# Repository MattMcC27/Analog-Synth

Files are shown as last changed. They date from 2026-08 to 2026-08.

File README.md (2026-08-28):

# Analog-Synth

My personal Analog Voltage Controlled Oscilator, wave shapers, and output stage
<p align="center">
  
</p>  

<p align="center">
  
</p>  

## Behavior

## Wave Shape Photos at decreasing frequency

<p align="center">
  
  
  
</p>  
<p align="center">
  
  
  
</p>  
<p align="center">
  
  
  
</p>  
<p align="center">
  
  
  
</p>  
<p align="center">
  
  
  
</p>  
<p align="center">
  
</p>  

## Audio Demo

https://github.com/user-attachments/assets/6dd11a05-b424-4769-ac00-267ce8dbd173

https://github.com/user-attachments/assets/6da5949c-7cdd-406b-b645-f12ac689b7d8

https://github.com/user-attachments/assets/ecf994ba-5ef1-4e04-878b-3f7e2e97198b

https://github.com/user-attachments/assets/66918d8a-2ba2-4e4a-80ee-363ddde3f1d2

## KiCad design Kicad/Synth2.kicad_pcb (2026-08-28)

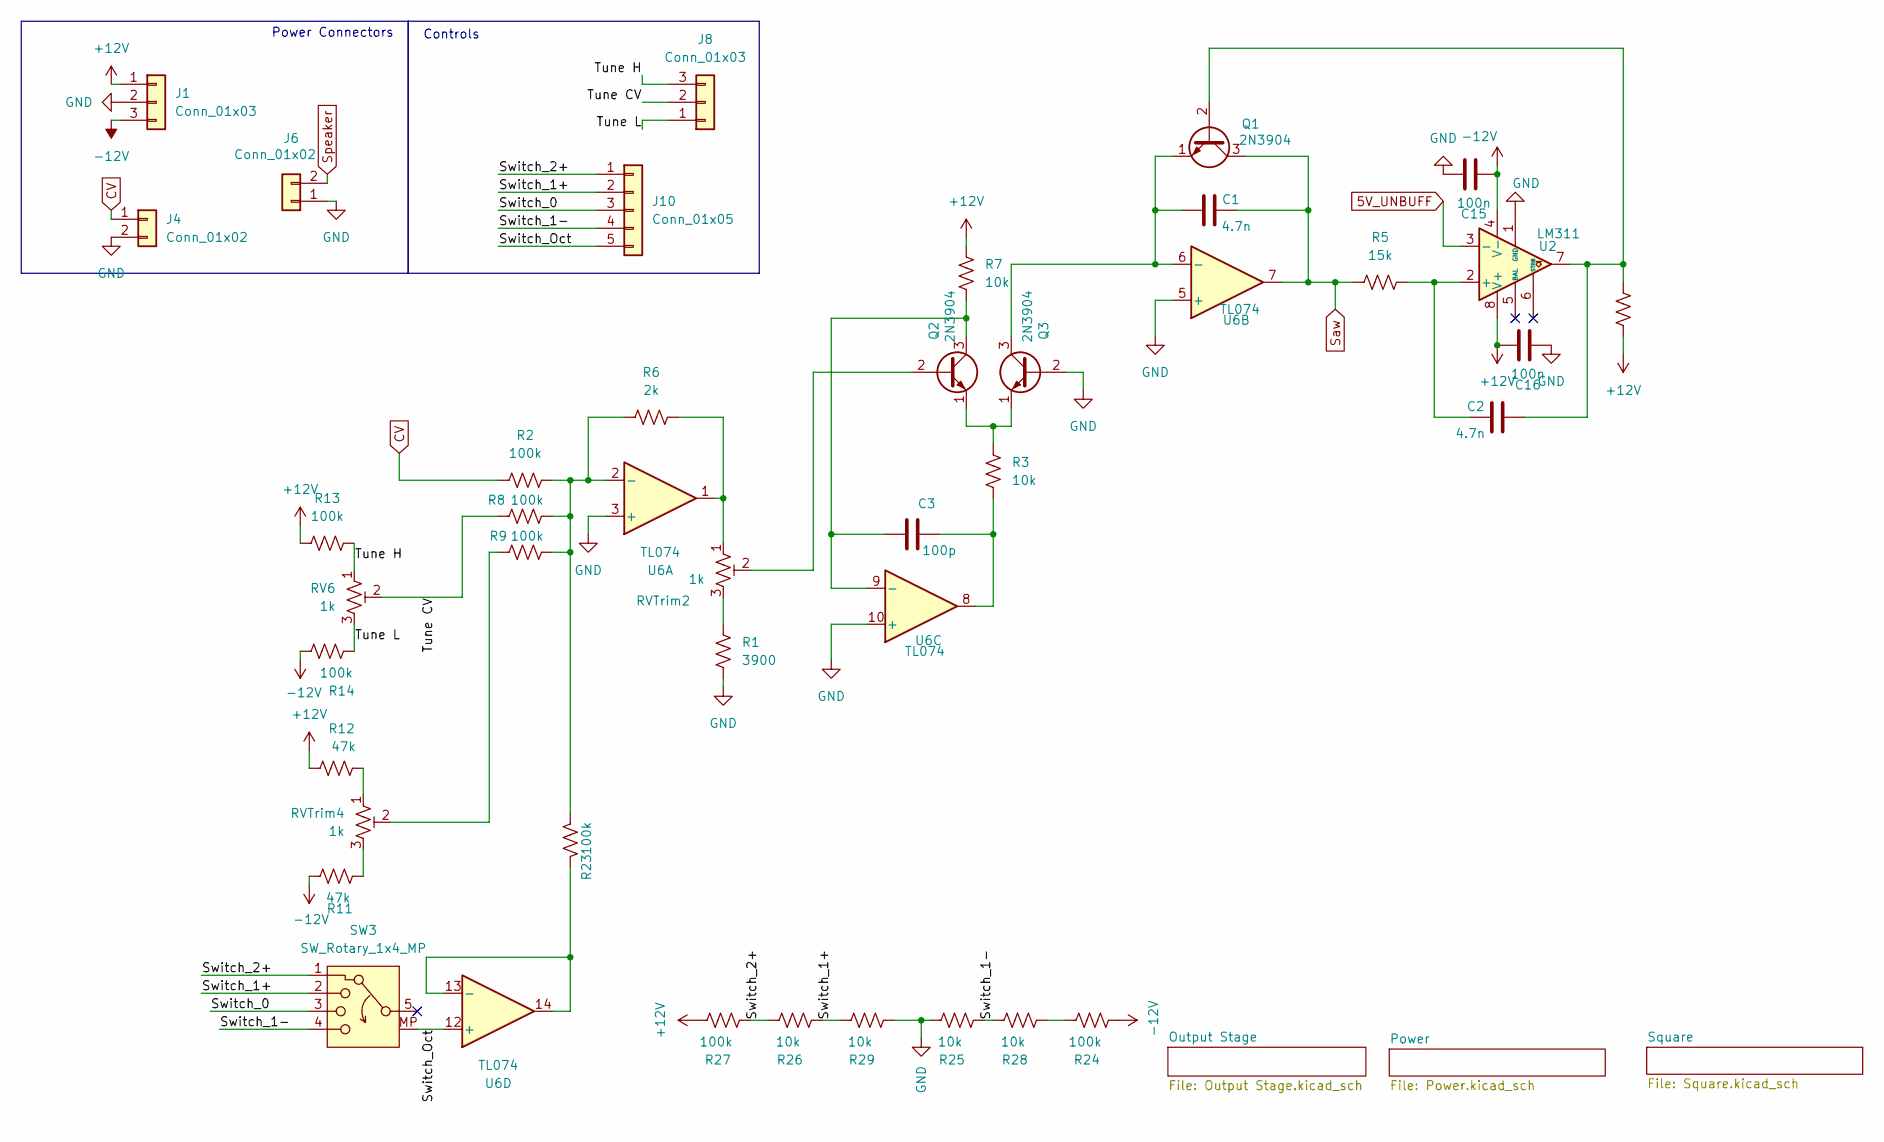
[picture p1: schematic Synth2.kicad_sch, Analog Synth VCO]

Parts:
C1, C2: 4.7n; C_Disc_D5.0mm_W2.5mm_P5.00mm
C3: 100p; C_Disc_D5.0mm_W2.5mm_P5.00mm
C15, C16: 100n; C_Disc_D5.0mm_W2.5mm_P5.00mm
J1, J8: Conn_01x03; JST_XH_B3B-XH-A_1x03_P2.50mm_Vertical
J4, J6: Conn_01x02; JST_XH_B2B-XH-A_1x02_P2.50mm_Vertical
J10: Conn_01x05; JST_XH_B5B-XH-A_1x05_P2.50mm_Vertical
Q1, Q2, Q3: 2N3904; MYNPN
R1: 3900; R_Axial_DIN0207_L6.3mm_D2.5mm_P7.62mm_Horizontal
R2, R8, R9, R13, R14, R23, R24, R27: 100k; R_Axial_DIN0207_L6.3mm_D2.5mm_P7.62mm_Horizontal
R3, R4, R7, R25, R26, R28, R29: 10k; R_Axial_DIN0207_L6.3mm_D2.5mm_P7.62mm_Horizontal
R5: 15k; R_Axial_DIN0207_L6.3mm_D2.5mm_P7.62mm_Horizontal
R6: 2k; R_Axial_DIN0207_L6.3mm_D2.5mm_P7.62mm_Horizontal
R11, R12: 47k; R_Axial_DIN0207_L6.3mm_D2.5mm_P7.62mm_Horizontal
RV6: 1k
RVTrim2, RVTrim4: 1k; Potentiometer_Bourns_3296W_Vertical
SW3: SW_Rotary_1x4_MP
U2: LM311; MY311
U6: TL074; MYTL074

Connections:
5V_UNBUFF: U2.3 (-); also elsewhere on the board
+12V: C16.2, J1.1, R4.1, R7.1, R12.2, R13.2, R27.1, U2.8 (V+); also elsewhere on the board
-12V: C15.1, J1.3, R11.2, R14.2, R24.2, U2.4 (V-); also elsewhere on the board
/Switch_0: J10.3, SW3.3
/Switch_1+: J10.2, R26.2, R29.1, SW3.2
/Switch_1-: J10.4, R25.2, R28.1, SW3.4
/Switch_2+: J10.1, R26.1, R27.2, SW3.1
/Switch_Oct: J10.5, SW3.MP, U6.12 (+)
/Tune CV: J8.2, R8.1, RV6.2
/Tune H: J8.3, R13.1, RV6.1
/Tune L: J8.1, R14.1, RV6.3
CV: J4.1, R2.1
GND: C15.2, C16.1, J1.2, J4.2, J6.1, Q3.2 (B), R1.2, R25.1, R29.2, U2.1 (GND), U6.3 (+), U6.5 (+), U6.10 (+); also elsewhere on the board
unnamed: C3.2, R3.2, U6.8
unnamed: C2.1, Q1.2 (B), R4.2, U2.7
unnamed: C1.1, Q1.1 (E), Q3.3 (C), U6.6 (-)
unnamed: Q2.2 (B), RVTrim2.2
unnamed: C3.1, Q2.3 (C), R7.2, U6.9 (-)
unnamed: Q2.1 (E), Q3.1 (E), R3.1
unnamed: R1.1, RVTrim2.3
unnamed: R6.2, RVTrim2.1, U6.1
unnamed: R9.1, RVTrim4.2
unnamed: R11.1, RVTrim4.3
unnamed: R12.1, RVTrim4.1
unnamed: R24.1, R28.2
unnamed: C2.2, R5.1, U2.2 (+)
unnamed: R2.2, R6.1, R8.2, R9.2, R23.2, U6.2 (-)
unnamed: R23.1, U6.13 (-), U6.14
Saw: C1.2, Q1.3 (C), R5.2, U6.7; also elsewhere on the board
Speaker: J6.2; also elsewhere on the board

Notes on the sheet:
Power Connectors
Controls

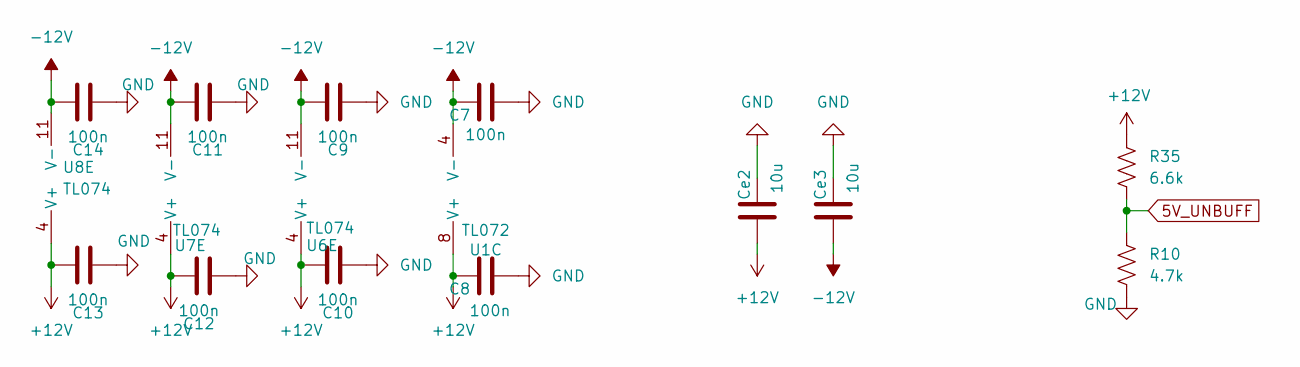
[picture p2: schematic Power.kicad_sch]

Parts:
C7, C8, C9, C10, C11, C12, C13, C14: 100n; C_Disc_D5.0mm_W2.5mm_P5.00mm
Ce2, Ce3: 10u; CP_Radial_D5.0mm_P2.50mm
R10: 4.7k; R_Axial_DIN0207_L6.3mm_D2.5mm_P7.62mm_Horizontal
R35: 6.6k; R_Axial_DIN0207_L6.3mm_D2.5mm_P7.62mm_Horizontal
U1: TL072; MYTL072
U6, U7, U8: TL074; MYTL074

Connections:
5V_UNBUFF: R10.2, R35.1; also elsewhere on the board
+12V: C8.2, C10.2, C12.1, C13.2, Ce2.1, R35.2, U1.8 (V+), U6.4 (V+), U7.4 (V+), U8.4 (V+); also elsewhere on the board
-12V: C7.2, C9.2, C11.2, C14.2, Ce3.1, U1.4 (V-), U6.11 (V-), U7.11 (V-), U8.11 (V-); also elsewhere on the board
GND: C7.1, C8.1, C9.1, C10.1, C11.1, C12.2, C13.1, C14.1, Ce2.2, Ce3.2, R10.1; also elsewhere on the board

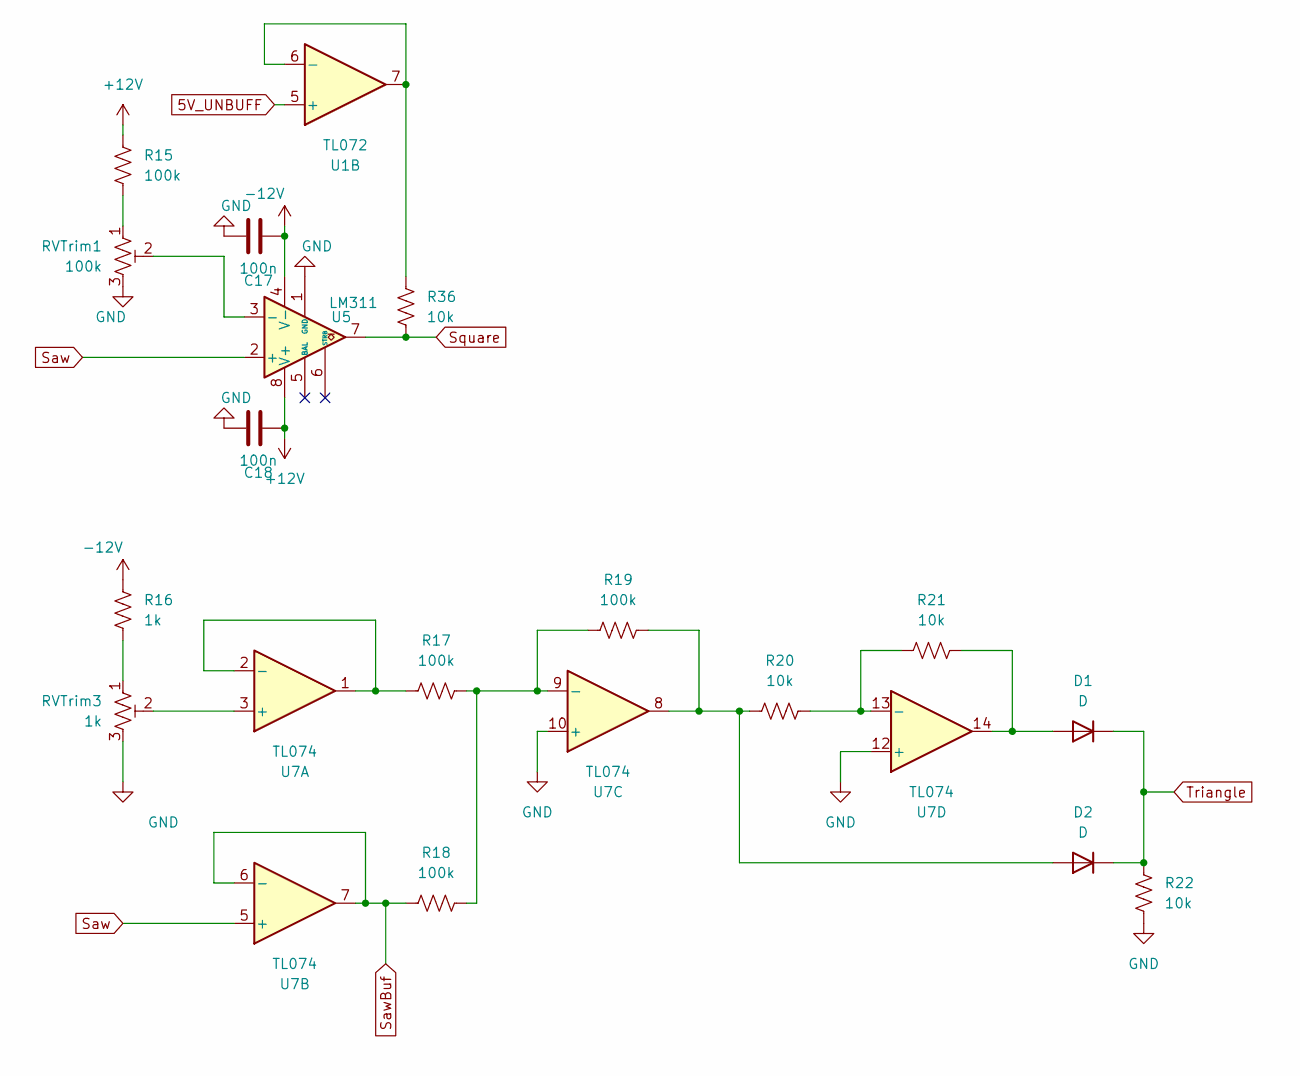
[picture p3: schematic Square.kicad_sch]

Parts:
C17, C18: 100n; C_Disc_D5.0mm_W2.5mm_P5.00mm
D1, D2: D; MYDIODE2
R15, R17, R18, R19: 100k; R_Axial_DIN0207_L6.3mm_D2.5mm_P7.62mm_Horizontal
R16: 1k; R_Axial_DIN0207_L6.3mm_D2.5mm_P7.62mm_Horizontal
R20, R21, R22, R36: 10k; R_Axial_DIN0207_L6.3mm_D2.5mm_P7.62mm_Horizontal
RVTrim1: 100k; Potentiometer_Bourns_3296W_Vertical
RVTrim3: 1k; Potentiometer_Bourns_3296W_Vertical
U1: TL072; MYTL072
U5: LM311; MY311
U7: TL074; MYTL074

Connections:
5V_UNBUFF: U1.5 (+); also elsewhere on the board
+12V: C18.1, R15.2, U5.8 (V+); also elsewhere on the board
-12V: C17.1, R16.2, U5.4 (V-); also elsewhere on the board
GND: C17.2, C18.2, R22.2, RVTrim1.3, RVTrim3.3, U5.1 (GND), U7.10 (+), U7.12 (+); also elsewhere on the board
unnamed: D1.2 (A), R21.1, U7.14
unnamed: D2.2 (A), R19.1, R20.2, U7.8
unnamed: R15.1, RVTrim1.1
unnamed: R16.1, RVTrim3.1
unnamed: R36.2, U1.6 (-), U1.7
unnamed: RVTrim1.2, U5.3 (-)
unnamed: RVTrim3.2, U7.3 (+)
unnamed: R17.2, U7.1, U7.2 (-)
unnamed: R17.1, R18.1, R19.2, U7.9 (-)
unnamed: R20.1, R21.2, U7.13 (-)
Saw: U5.2 (+), U7.5 (+); also elsewhere on the board
SawBuf: R18.2, U7.6 (-), U7.7; also elsewhere on the board
Square: R36.1, U5.7; also elsewhere on the board
Triangle: D1.1 (K), D2.1 (K), R22.1; also elsewhere on the board

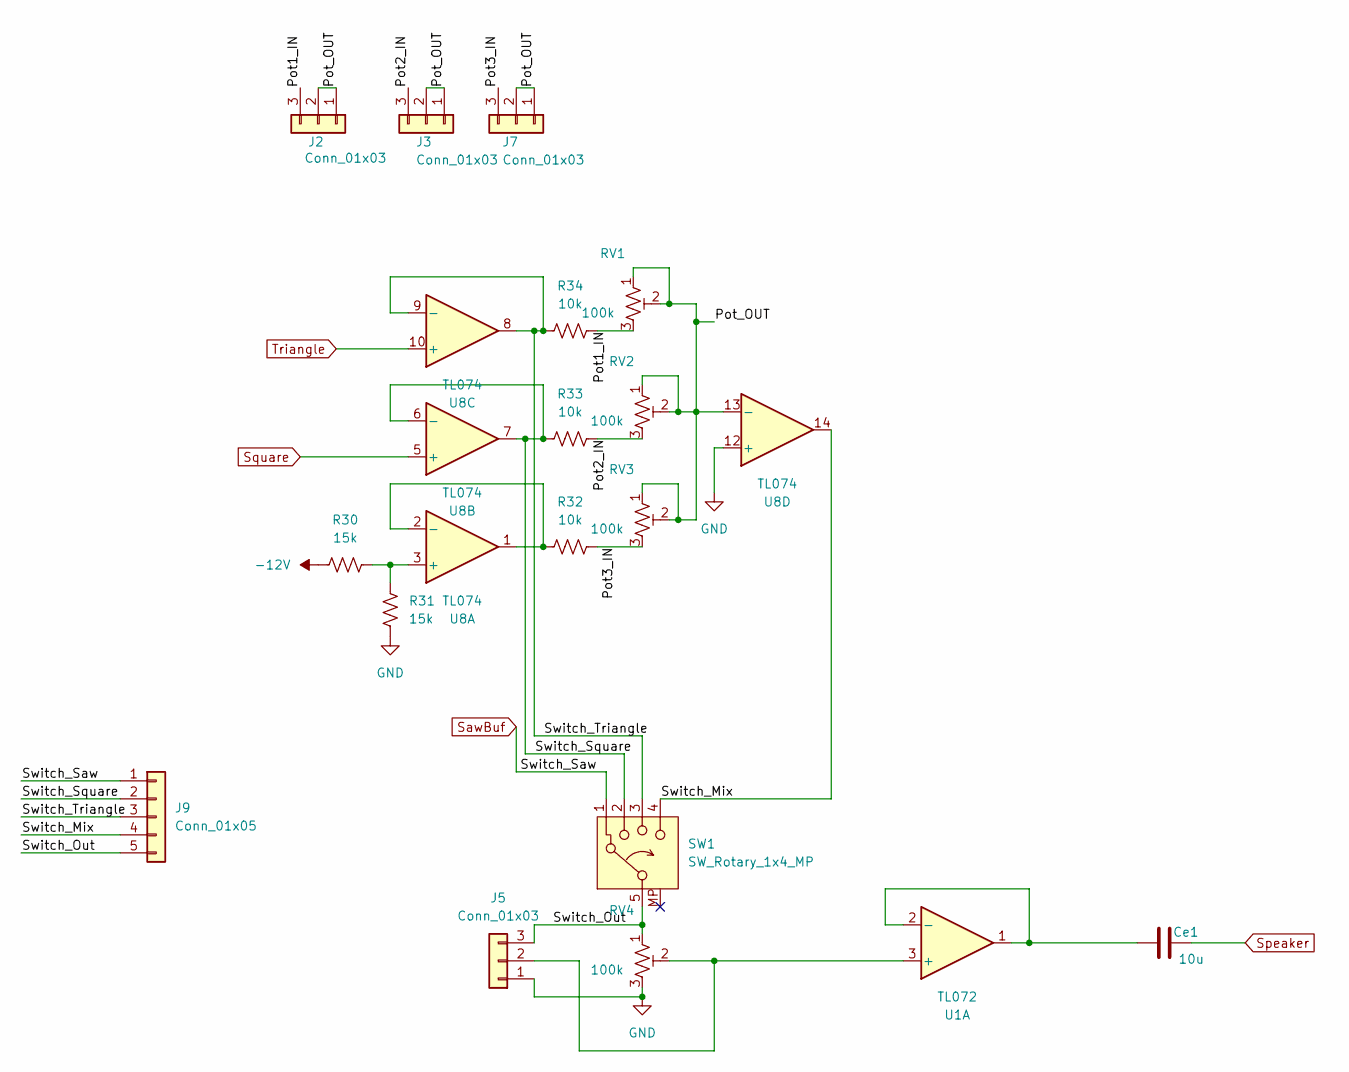
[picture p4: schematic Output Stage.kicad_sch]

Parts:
Ce1: 10u; CP_Radial_D5.0mm_P2.50mm
J2, J3, J5, J7: Conn_01x03; JST_XH_B3B-XH-A_1x03_P2.50mm_Vertical
J9: Conn_01x05; JST_XH_B5B-XH-A_1x05_P2.50mm_Vertical
R30, R31: 15k; R_Axial_DIN0207_L6.3mm_D2.5mm_P7.62mm_Horizontal
R32, R33, R34: 10k; R_Axial_DIN0207_L6.3mm_D2.5mm_P7.62mm_Horizontal
RV1, RV2, RV3, RV4: 100k
SW1: SW_Rotary_1x4_MP
U1: TL072; MYTL072
U8: TL074; MYTL074

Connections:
-12V: R30.2; also elsewhere on the board
/Output Stage/Pot1_IN: J2.3, R34.1, RV1.3
/Output Stage/Pot2_IN: J3.3, R33.1, RV2.3
/Output Stage/Pot3_IN: J7.3, R32.1, RV3.3
/Output Stage/Pot_OUT: J2.1, J2.2, J3.1, J3.2, J7.1, J7.2, RV1.1, RV1.2, RV2.1, RV2.2, RV3.1, RV3.2, U8.13 (-)
/Output Stage/Switch_Mix: J9.4, SW1.4, U8.14
/Output Stage/Switch_Out: J5.3, J9.5, RV4.1, SW1.5
/Output Stage/Switch_Square: J9.2, R33.2, SW1.2, U8.6 (-), U8.7
/Output Stage/Switch_Triangle: J9.3, R34.2, SW1.3, U8.8, U8.9 (-)
GND: J5.1, R31.1, RV4.3, U8.12 (+); also elsewhere on the board
unnamed: J5.2, RV4.2, U1.3 (+)
unnamed: Ce1.1, U1.1, U1.2 (-)
unnamed: R30.1, R31.2, U8.3 (+)
unnamed: R32.2, U8.1, U8.2 (-)
SawBuf: J9.1, SW1.1; also elsewhere on the board
Speaker: Ce1.2; also elsewhere on the board
Square: U8.5 (+); also elsewhere on the board
Triangle: U8.10 (+); also elsewhere on the board

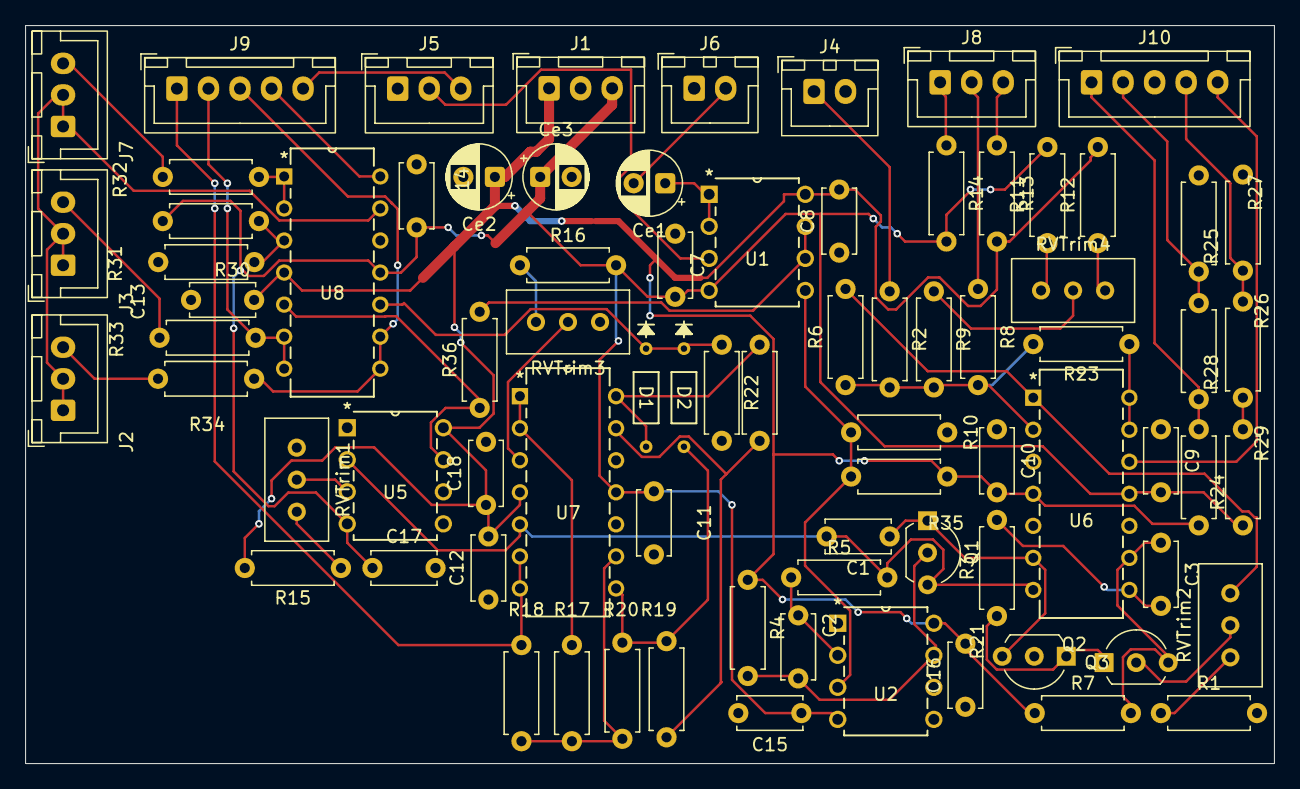
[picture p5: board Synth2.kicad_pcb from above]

Board: 2 copper layers, 99.0 x 58.5 mm, 79 parts (0 on the bottom side), 54 nets.
